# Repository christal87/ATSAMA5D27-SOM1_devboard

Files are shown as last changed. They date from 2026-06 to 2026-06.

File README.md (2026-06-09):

# ATSAMA5D27-SOM1_devboard

A custom SAMA5D27 development board I made a while ago for personal experimentation. It's exposing the parallel NAND flash interface to get some hands-on experience using that as a traditional embedded boot device.  

#### TODO:
- [x] PMIC power sequencing works, voltage regulation feedbacks valid, ripple low
- [x] board unique ID readable
- [x] serial console works
- [x] RTC backup supercap works
- [x] default SDMMC0 boots
- [x] USB host VBUS present
- [x] USB High Speed host works
- [x] NAND r/w test OK
- [ ] Configure NAND IOSET and boot config
- [ ] Implement NAND support in the at91bootstrap 2nd level bootloader and U-Boot
- [ ] Compile a kernel and make a rootfs that boots from NAND (buildroot/linux4sam custom board and kernel configs)
- [ ] test (Q)SPI interfaces
- [ ] use (Q)SPI to store the bootloader as NVM
- [ ] test other interfaces (JTAG, UARTs, USB device, ethernet, I^2C, SPI, PIOBU, HSIC)
- [ ] bonus: design and add an eMMC breakout board

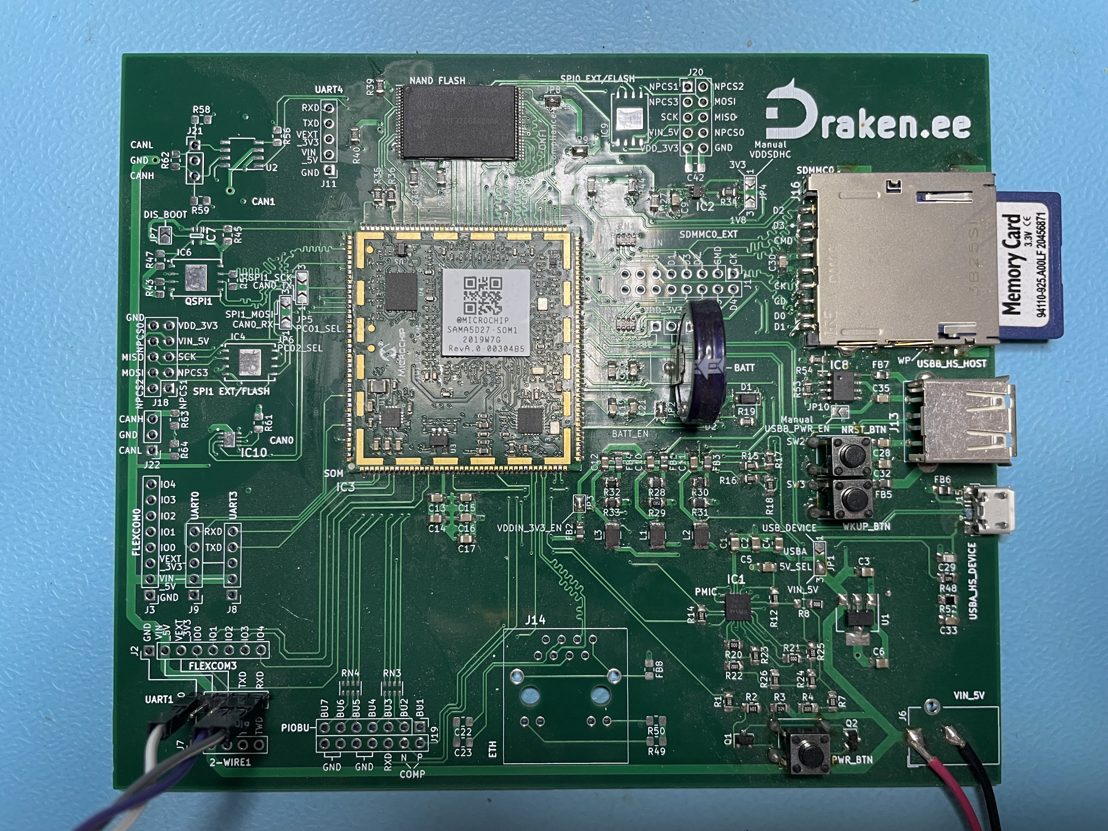
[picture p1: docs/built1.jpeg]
ATSAMA5D27-SOM1_devboard_built1 ATSAMA5D27-SOM1 devboard built


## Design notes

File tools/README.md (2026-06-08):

# sam-ba v3.7 boot assistant tool cheat sheet (via serial)

#### Board serial connection test by reading the device's unique ID
```
./sam-ba -p serial:ttyUSB0 -b sama5d27-som1 -a readuniqueid
```

#### This is the default state of boot config registers and fuses before changes

Read fuse:  
```
./sam-ba -t 5 -p serial:ttyUSB0 -b sama5d27-som1 -a bootconfig -c readcfg:fuse
Opening serial port 'ttyUSB0'
Connection opened.
Executing command 'readcfg:fuse'
FUSE=0x00000000 / QSPI0_IOSET1,QSPI1_IOSET1,SPI0_IOSET1,SPI1_IOSET1,NFC_IOSET1,SDMMC0,SDMMC1,UART1_IOSET1,JTAG_IOSET1
Connection closed.
```

Read BUREG[0:3]:  
```
./sam-ba -t 5 -p serial:ttyUSB0 -b sama5d27-som1 -a bootconfig -c readcfg:bureg0
Opening serial port 'ttyUSB0'
Connection opened.
Executing command 'readcfg:bureg0'
BUREG0=0x00000000 / QSPI0_IOSET1,QSPI1_IOSET1,SPI0_IOSET1,SPI1_IOSET1,NFC_IOSET1,SDMMC0,SDMMC1,UART1_IOSET1,JTAG_IOSET1
Connection closed.

./sam-ba -t 5 -p serial:ttyUSB0 -b sama5d27-som1 -a bootconfig -c readcfg:bureg1
Opening serial port 'ttyUSB0'
Connection opened.
Executing command 'readcfg:bureg1'
BUREG1=0x00000000 / QSPI0_IOSET1,QSPI1_IOSET1,SPI0_IOSET1,SPI1_IOSET1,NFC_IOSET1,SDMMC0,SDMMC1,UART1_IOSET1,JTAG_IOSET1
Connection closed.

./sam-ba -t 5 -p serial:ttyUSB0 -b sama5d27-som1 -a bootconfig -c readcfg:bureg2
Opening serial port 'ttyUSB0'
Connection opened.
Executing command 'readcfg:bureg2'
BUREG2=0x00000000 / QSPI0_IOSET1,QSPI1_IOSET1,SPI0_IOSET1,SPI1_IOSET1,NFC_IOSET1,SDMMC0,SDMMC1,UART1_IOSET1,JTAG_IOSET1
Connection closed.

./sam-ba -t 5 -p serial:ttyUSB0 -b sama5d27-som1 -a bootconfig -c readcfg:bureg3
Opening serial port 'ttyUSB0'
Connection opened.
Executing command 'readcfg:bureg3'
BUREG3=0x00000000 / QSPI0_IOSET1,QSPI1_IOSET1,SPI0_IOSET1,SPI1_IOSET1,NFC_IOSET1,SDMMC0,SDMMC1,UART1_IOSET1,JTAG_IOSET1
Connection closed.
```

Read BSCR:  
```
draken@christal-oldlaptop2:~/Downloads/sam-ba_3.5$ ./sam-ba -t 5 -p serial:ttyUSB0 -b sama5d27-som1 -a bootconfig -c readcfg:bscr
Opening serial port 'ttyUSB0'
Connection opened.
Executing command 'readcfg:bscr'
BSCR=0x00000000 / BUREG0
Connection closed.
```

#### Set SDMMC0 boot
Set up BUREG0 to boot from SDMMC0 with various IOSETs, then activate it by making it valid in the BSCR  

```
./sam-ba -t 5 -p serial:ttyUSB0 -b sama5d27-som1 -a bootconfig -c writecfg:bureg0:SDMMC0,SDMMC1_DISABLED,NFC_IOSET1,QSPI0_DISABLED,QSPI1_IOSET2,SPI0_IOSET1,SPI1_DISABLED,JTAG_IOSET3,QSPI_XIP_MODE,EXT_MEM_BOOT
./sam-ba -t 5 -p serial:ttyUSB0 -b sama5d27-som1 -a bootconfig -c writecfg:bscr:bureg0,valid
./sam-ba -t 5 -p serial:ttyUSB0 -b sama5d27-som1 -a bootconfig -c readcfg:bscr
```

#### SDMMC read test into file

Read 1024 bytes at offset 0 to a file from SDMMC0, IOSET1, 1st boot partition, 4-line I/O, at 3.3V level  
```
./sam-ba -p serial:ttyUSB0 -b sama5d27-som1 -t 5 -a sdmmc:0:1:1:4:4 -c read:firmware.bin:0x0:1024
```

#### NAND modification steps
**Notice: Only set fuses when they are to be permanent (in production)! Until then configs are held until RTC is powered down.**
1. Leave factory default DISABLE_BSCR (bit 22) as 0
2. Set BUREG_VALID if not already 1
3. Leave factory default BUREG_INDEX which has to be 0
4. Set up the correct BUREG_x according to the previously read index value
5. Set EXT_MEM_BOOT_ENABLE to 1 for using NAND, etc. flash
    - https://microchip.my.site.com/s/article/How-to-configure-the-PMECC
    - https://www.linux4sam.org/bin/view/Linux4SAM/PmeccConfigure
    - https://github.com/ARM-software/u-boot/blob/master/doc/README.nand
6. Set the correct PMECC header to configure the BCH algorithm for the NAND flash interface ECC controller
```
     example header: 0xc0098da5 - 0b1100 0 000000010 01 100 011011010 010 1
     key bits[31:28] - 1100 - decimal 12 or 0x0c must be written here to validate the content of the whole word
     bit[27] - not used, leave set to 0
     eccOffset bits[26:18] - 000000010 - 2: 2 byte offset of the first ECC byte in the spare zone
     sectorSize bits[17:16] - 01 - 1: For 1024 bytes per sector
     eccBitReq bits[15:13] - 100 - 4: 24-bit ECC
     spareSize bits[12:4] - 011011010 - 218 bytes
     nbSectorPerPage bits[3:1] - 010 - 2 sectors per page
     usePmecc bits[0] - 1 - use PMECC
```

#### NAND PMECC header according to the data sheet of a Micron MT29F32G08ABAAAWP-ITZ:A
Flash parameters:  
```
page (main) area size: 8192bytes
page OOB (spare) area size: 448bytes
block size: 1024K (56K OOB total per block)
plane size: 2 planes (2048blocks * 2) 
device size: 2 planes or 4096 blocks
erase block (sector) size: 1024k
minimum advised ECC: 8-bit BCH
```

Derived header: 0xc0e14387 - 0b 1100 0 000111000 01 010 000111000 011 1 (according to doc/nandflash.html)  
```
key bits[31:28] - 1100 - decimal 12 or 0x0c must be written here to validate the content of the whole word
bit[27] - not used, leave set to 0
eccOffset bits[26:18] - 000111000 - 56: datasheet: First spare area location: Byte 8192, 56 byte offset of the first ECC byte in the spare zone (app dependent) | Linux4sam: oob (spareSize) size - (PMECC encode data size * sector number per page): 56 - ( 14 x 8 ) = -56
sectorSize bits[17:16] - 01 - 1: For 1024 bytes per sector (determined by the user, sometimes called erase block size?)
eccBitReq bits[15:13] - 010 - 2: 8-bit ECC
spareSize bits[12:4] - 000111000 - 56 bytes (datasheet 114 bytes total / 8 sector = 56, spare area for ECC and wear levelling, minimum value: N = Number of ECC bytes x Sectors Per Page: 14 x 8 = 112)
nbSectorPerPage bits[3:1] - 011 - 8 sectors per page (depends on sectorSize and page size of the NAND, nbSectorPerPage * sectorSize = page size: 8 * 1024 = 8192)
usePmecc bits[0] - 1 - use PMECC
```

#### NAND flash read/write test (IOSET1, 8-bit bus, previously calculated PM ECC header)
First check if it's empty already then test by downloading a 1kByte dummy "hello world" binary to the target. Read back the previously written binary and verify using hexdump.  
```
./sam-ba -t 5 -p serial:ttyUSB0 -b sama5d27-som1 -a nandflash:1:8:0xc0e14387 -c read:firmware.bin::1024
./sam-ba -t 5 -p serial:ttyUSB0 -b sama5d27-som1 -a nandflash:1:8:0xc0e14387 -c write:firmware.bin
./sam-ba -t 5 -p serial:ttyUSB0 -b sama5d27-som1 -a nandflash:1:8:0xc0e14387 -c read:firmware_written.bin::1024
hexdump firmware_written.bin
```

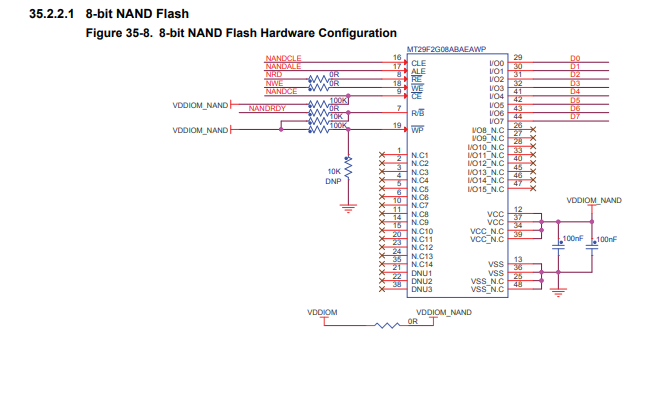
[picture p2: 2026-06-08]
docs/8bit_NAND_sch.png

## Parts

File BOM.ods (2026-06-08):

Ref. Des. | Available | Planned | Mouser URL | Qty | Mouser Part
C5, C10-C12 | CL21A475KPFNNNG | CL21A475KPFNNNG | https://hu.mouser.com/ProductDetail/Samsung-Electro-Mechanics/CL21A475KPFNNNG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 | 4 | 187-CL21A475KPFNNNG
C7 | 1F/5.5V | supercap |  | 1
C14, C17, C20, C21 | CL21A225KOFNNNE | CL21A225KOFNNNE | https://hu.mouser.com/ProductDetail/Samsung-Electro-Mechanics/CL21A225KOFNNNE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 | 4 | 187-CL21A225KOFNNNE
C8, C9, C13, C15, C16, C18, C19, C22, C23, C25-C28, C30, C31, C33-C38, C41-C43 | C0805C104M5RACTU | C0805C104M5RACTU | https://hu.mouser.com/ProductDetail/KEMET/C0805C104M5RACTU?qs=VOOUd%252Bza08qHu13WgNByHQ%3D%3D | 24 | 80-C0805C104M5R
C29 | C0805C200J5HACTU | C0805C200J5HACTU | https://hu.mouser.com/ProductDetail/KEMET/C0805C200J5HACTU?qs=W0yvOO0ixfGLt%252BzU2G34sQ%3D%3D | 1 | 80-C0805C200J5HACTU
C1-C4, C6, C24, C32 | CL21A106KAYNNNG | CL21A106KAYNNNG | https://hu.mouser.com/ProductDetail/Samsung-Electro-Mechanics/CL21A106KAYNNNG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 | 7 | 187-CL21A106KAYNNNG
C39, C40 | C0805C561M5RACTU | C0805C561M5RACTU | https://hu.mouser.com/ProductDetail/KEMET/C0805C561M5RACTU?qs=dntjzo9IpHrXGYTvsoaVYg%3D%3D | 2 | 80-C0805C561M5RACTU
D1 | STPS1L60ZF | STPS1L60ZF | https://hu.mouser.com/ProductDetail/STMicroelectronics/STPS1L60ZF?qs=xjeEZJU9OeMcvgJ4Z2%252BLPg%3D%3D | 1 | 511-STPS1L60ZF
D2 | BAT54C | BAT54C | https://hu.mouser.com/ProductDetail/Diotec-Semiconductor/BAT54C?qs=OlC7AqGiEDmkBJ3TS7AJwQ%3D%3D | 1 | 637-BAT54C
FB1-FB8 | BLM21SP181SH1D | BLM21SP181SH1D | https://hu.mouser.com/ProductDetail/Murata-Electronics/BLM21SP181SH1D?qs=byeeYqUIh0PxkBeBHE6ZPA%3D%3D | 8 | 81-BLM21SP181SH1D
IC1 | MIC23451-AAAYFL-T5 | MIC23451-AAAYFL-T5 | https://hu.mouser.com/ProductDetail/Microchip-Technology/MIC23451-AAAYFL-T5?qs=Y3Q3JoKAO1SH2PbgnVFIbQ%3D%3D | 1 | 998-MIC23451-AAAYFL
IC2 | TMUX1219DCKR | TMUX1219DCKR | https://hu.mouser.com/ProductDetail/Texas-Instruments/TMUX1219DCKR?qs=T3oQrply3y%252BxotOOfamVjQ%3D%3D | 1 | 595-TMUX1219DCKR
IC3 | ATSAMA5D27-SOM1 | ATSAMA5D27-SOM1 |  | 1
IC5 | MT29F32G08ABAAAWP-ITZ:A | MT29F32G08CBADBWP-12IT:D | https://hu.mouser.com/ProductDetail/Micron/MT29F32G08ABAAAWP-ITZA?qs=rrS6PyfT74fB1JX2ERU8Ug%3D%3D | 1 | 340-200226-TRAY
IC4, IC6, IC9 | IS25LP512M-JLLE | IS25LP512M-JLLE | https://hu.mouser.com/ProductDetail/ISSI/IS25LP512M-JLLE?qs=W0yvOO0ixfEtOjO9H9UVUg%3D%3D | 3 | 870-IS25LP512M-JLLE
IC7 | NL17SZ126DFT2G | NL17SZ126DFT2G | https://hu.mouser.com/ProductDetail/onsemi/NL17SZ126DFT2G-L22038?qs=vvQtp7zwQdOwMaO9ubYIuw%3D%3D | 1 | 863-Z126DFT2G-L22038
IC8 | MIC2075-1YM (/w th. Shdn.) | MIC2025-1YM | https://hu.mouser.com/ProductDetail/Microchip-Technology/MIC2075-1YM?qs=aiLzH1moG31jWXLy5NeZyA%3D%3D | 1 | 998-MIC2075-1YM
IC10 | ATA6561-GBQW-N | ATA6561-GBQW-N | https://hu.mouser.com/ProductDetail/Microchip-Technology/ATA6561-GBQW-N?qs=y6ZabgHbY%252BxuRHjTmdpZUA%3D%3D | 1 | 579-ATA6561-GBQW-N
J2, J3 | 22-28-4080 | 22-28-4080 |  | 2
J4 | 22-28-4020 | 22-28-4020 |  | 1
J5 | 77313-101-10LF | 77313-101-10LF |  | 1
J6 | PJ-102AH | PJ-102AH | https://hu.mouser.com/ProductDetail/CUI-Devices/PJ-102AH?qs=WyjlAZoYn50Yq4CrVLCXLw%3D%3D | 1 | 490-PJ-102AH
J7-J11 | 22-28-4050 | 22-28-4050 |  | 5
J13 | 87520-0010BLF | 87520-0010BLF | https://hu.mouser.com/ProductDetail/Amphenol-FCI/87520-0010BLF?qs=x6EjVpvqMVP%2F2to87x7cdQ%3D%3D | 1 | 649-87520-0010BLF
J14 | 5-2337992-4 (w/o PoE: KRJ45-109NL) | chinese eth magnetics | https://hu.mouser.com/ProductDetail/TE-Connectivity/5-2337992-4?qs=l4Gc20tDgJLHtal8kumJHQ%3D%3D | 1 | 571-5-2337992-4
J15 | 10103594-0001LF | 10103594-0001LF | https://hu.mouser.com/ProductDetail/Amphenol-FCI/10103594-0001LF?qs=EnLMdcWnKABYZwdMsmC%2Fag%3D%3D | 1 | 649-10103594-0001LF
J16 | DM1AA-SF-PEJ(82) | DM1AA-SF-PEJ(21) | https://hu.mouser.com/ProductDetail/Hirose-Connector/DM1AA-SF-PEJ82?qs=q%252B4FLHukgWBHaRKRr0HV%252Bw%3D%3D | 1 | 798-DM1AA-SF-PEJ82
J17 | 77313-101-16LF | 77313-101-16LF |  | 1
J18, J20 | 77313-101-10LF | 77313-101-10LF |  | 2
J19 | 77313-101-14LF | 77313-101-14LF |  | 1
J21, J22 | 22-28-4030 | 22-28-4030 |  | 2
L1-L3 | BRL3225T1R0M | BRL3225T1R0M | https://hu.mouser.com/ProductDetail/TAIYO-YUDEN/BRL3225T1R0M?qs=I6KAKw0tg2yR41WK9kXmMw%3D%3D | 3 | 963-BRL3225T1R0M
Q1, Q2 | BSS138-7-F | BSS138-7-F | https://hu.mouser.com/ProductDetail/Diodes-Incorporated/BSS138-7-F?qs=TJSU9qitBVRAP5gIAnNy0g%3D%3D | 2 | 621-BSS138-7-F
R28 | CRCW0805301KFKEA | CRCW0805301KFKEA | https://hu.mouser.com/ProductDetail/Vishay-Dale/CRCW0805301KFKEA?qs=YsYeyRVmgbTwvk7N3KDdww%3D%3D | 1 | 71-CRCW0805-301K-E3
R29 | CRCW0805158KFKEA | CRCW0805158KFKEA | https://hu.mouser.com/ProductDetail/Vishay-Dale/CRCW0805158KFKEA?qs=bMjB6bAaLEPYp%2Fg%252B8t1fcA%3D%3D | 1 | 71-CRCW0805158KFKEA
R30, R32 | CRCW0805309KFKEA | CRCW0805309KFKEA | https://hu.mouser.com/ProductDetail/Vishay-Dale/CRCW0805309KFKEA?qs=TrAHXYCGmqzIoat3yDoJTQ%3D%3D | 2 | 71-CRCW0805309KFKEA
R31, R33 | CRCW080571K5FKEA | CRCW080571K5FKEA | https://hu.mouser.com/ProductDetail/Vishay-Dale/CRCW080571K5FKEA?qs=Lu3mkJd%252BoBEibXcVy2xPUw%3D%3D | 2 | 71-CRCW0805-71.5K-E3
R6-R8, R10, R20, R21, R34-R36, R38, R60, R61, R63, R64 | CRCW08050000Z0EAC | CRCW08050000Z0EAC | https://hu.mouser.com/ProductDetail/Vishay-Dale/CRCW08050000Z0EAC?qs=E3Y5ESvWgWMnvHb9ZvShmA%3D%3D | 14 | 71-CRCW08050000Z0EAC
R42 | CRCW080510K0FKEAC | CRCW080510K0FKEAC |  | 1
R2, R3, R9, R11, R13, R17, R37, R40, R48 | CRCW0805100KJNEAC | CRCW0805100KJNEAC | https://hu.mouser.com/ProductDetail/Vishay-Dale/CRCW0805100KJNEAC?qs=E3Y5ESvWgWMMFQOyHSPe4Q%3D%3D | 9 | 71-CRCW0805100KJNEAC
R49, R50 | CRCW0805470RFKEAC | CRCW0805470RFKEAC | https://hu.mouser.com/ProductDetail/Vishay-Dale/CRCW0805470RFKEAC?qs=E3Y5ESvWgWPsF5leBpDSrQ%3D%3D | 2 | 71-CRCW0805470RFKEAC
R52 | CRCW0805200KJNEA | CRCW0805200KJNEAC | https://hu.mouser.com/ProductDetail/Vishay-Dale/CRCW0805200KJNEA?qs=t6Mf8e9K%2Fuk6Viblk4xGKg%3D%3D | 1 | 71-CRCW0805200KJNEA
R1, R4, R5, R14, R18, R22-R27, R39, R41, R43-R47, R51, R53, R54, R56 | CRCW080510K0FKEAC | CRCW080510K0FKEAC | https://hu.mouser.com/ProductDetail/Vishay-Dale/CRCW080510K0FKEAC?qs=E3Y5ESvWgWORadmUijPtxQ%3D%3D | 22 | 71-CRCW080510K0FKEAC
R55 | CRCW080522K0FKEAC | CRCW080522K0FKEAC | https://hu.mouser.com/ProductDetail/Vishay-Dale/CRCW080522K0FKEAC?qs=E3Y5ESvWgWM%252BLh7gNR1oHw%3D%3D | 1 | 71-CRCW080522K0FKEAC
R57 | CRCW08054K70FKEAC | CRCW08054K70FKEAC | https://hu.mouser.com/ProductDetail/Vishay-Dale/CRCW08054K70FKEAC?qs=E3Y5ESvWgWOQAAVugewEHA%3D%3D | 1 | 71-CRCW08054K70FKEAC
R12, R15, R16, R19, R58, R59 | CRCW0805100RFKEAC | CRCW0805100RFKEAC | https://hu.mouser.com/ProductDetail/Vishay-Dale/CRCW0805100RFKEAC?qs=E3Y5ESvWgWM6LN%2Fsc41QGg%3D%3D | 6 | 71-CRCW0805100RFKEAC
R62 | CRCW0805120RFKEAC | CRCW0805120RFKEAC | https://hu.mouser.com/ProductDetail/Vishay-Dale/CRCW0805120RFKEAC?qs=E3Y5ESvWgWNkSFxCW%252BJprQ%3D%3D | 1 | 71-CRCW0805120RFKEAC
RN1, RN2 | CAT16-683J4LF | CAY16-683J4LF | https://hu.mouser.com/ProductDetail/Bourns/CAT16-683J4LF?qs=RWPSkEkPOWwoZjhdciY8Mw%3D%3D | 2 | 652-CAT16-683J4LF
RN3, RN4 | CAT16-331J4LF | CAY16-331J4LF | https://hu.mouser.com/ProductDetail/Bourns/CAT16-331J4LF?qs=FaUPen95qPZGHrhxk7z1MA%3D%3D | 2 | 652-CAT16-331J4LF
SW1-SW3 | PTS645SM43SMTR92LFS | simple pushbutton |  | 3
U1 | AZ1117CR-3.3TRG1 | LM1117-3.3 | https://hu.mouser.com/ProductDetail/Diodes-Incorporated/AZ1117CR-3.3TRG1?qs=FKu9oBikfSlEg7waHw2tMw%3D%3D | 1 | 621-AZ1117CR-3.3TRG1
U2 | MCP2551-I/SN | MCP2551-I/SN | https://hu.mouser.com/ProductDetail/Microchip-Technology/MCP2551-I-SN?qs=9y3LFqDLL8L5zFfqqxdOHg%3D%3D | 1 | 579-MCP2551-I/SN

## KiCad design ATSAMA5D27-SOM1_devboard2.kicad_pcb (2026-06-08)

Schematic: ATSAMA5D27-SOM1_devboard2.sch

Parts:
C1, C2, C3, C4, C6, C24, C32: 10uF/25V; C_0805_2012Metric_Pad1.15x1.40mm_HandSolder; Part CL21A106KAYNNNG
C5, C10, C11, C12: 4.7uF/10V; C_0805_2012Metric_Pad1.15x1.40mm_HandSolder; Part CL21A475KPFNNNG
C7: 1F/5.5V; C_Disc_D11.0mm_W5.0mm_P5.00mm
C8, C9, C13, C15, C16, C18, C19, C22, C23, C25, C26, C27, C28, C30, C31, C33, C34, C35, C36, C37, C38, C41, C42, C43: 100nF; C_0805_2012Metric_Pad1.15x1.40mm_HandSolder; Part C0805C104M5RACTU
C14, C17, C20, C21: 2.2uF/16V; C_0805_2012Metric_Pad1.15x1.40mm_HandSolder; Part CL21A225KOFNNNE
C29: 20pF; C_0805_2012Metric_Pad1.15x1.40mm_HandSolder; Part C0805C200J5HACTU
C39, C40: 560pF; C_0805_2012Metric_Pad1.15x1.40mm_HandSolder; Part C0805C561M5RACTU
D1: STPS1L60ZF; D_SOD-123; Part STPS1L60ZF
D2: BAT54C; SOT-23; Part BAT54C
FB1, FB2, FB3, FB4, FB5, FB6, FB7, FB8: 180R; L_0805_2012Metric_Pad1.15x1.40mm_HandSolder; Part BLM21SP181SH1D
IC1: MIC23451-AAAYFL-T5; MIC23451AAAYFLT5; Manufacturer_Part_Number MIC23451-AAAYFL-T5; Mouser Part Number 998-MIC23451-AAAYFL
IC2: TMUX1219DCKR; SOT65P210X110-6N; Manufacturer_Part_Number TMUX1219DCKR; Mouser Part Number 595-TMUX1219DCKR
IC3: ATSAMA5D27-SOM1; ATSAMA5D27SOM1; Manufacturer_Part_Number ATSAMA5D27-SOM1; Mouser Part Number 556-ATSAMA5D27-SOM1
IC4, IC6, IC9: IS25LP512M-JLLE; SON127P800X600X80-9N; Manufacturer_Part_Number IS25LP512M-JLLE; Mouser Part Number 870-IS25LP512M-JLLE
IC5: MT29F32G08CBADBWP-12IT:D; SOP50P2000X120-48N; Manufacturer_Part_Number MT29F32G08ABAAAWP-ITZ:A; Mouser Part Number 340-200226-TRAY
IC7: NL17SZ126DFT2G; SOT65P210X110-5N; Manufacturer_Part_Number NL17SZ126DFT2G; Mouser Part Number 863-NL17SZ126DFT2G
IC8: MIC2025-1YM; SOIC127P602X173-8N; Manufacturer_Part_Number MIC2025-1YM; Mouser Part Number 998-MIC2025-1YM
IC10: ATA6561-GBQW-N; SON65P300X300X90-9N-D; Manufacturer_Part_Number ATA6561-GBQW-N; Mouser Part Number 579-ATA6561-GBQW-N
J2, J3: 22-28-4080; PinHeader_1x08_P2.54mm_Vertical; Part 22-28-4080
J4: 22-28-4020; PinHeader_1x02_P2.54mm_Vertical; Part 22-28-4020
J5: 77313-101-10LF; PinHeader_2x05_P2.54mm_Vertical_SMD; Part 77313-101-10LF
J6: PJ-102AH; BarrelJack_CUI_PJ-102AH_Horizontal; Part PJ-102AH
J7, J8, J9, J10, J11: 22-28-4050; PinHeader_1x05_P2.54mm_Vertical; Part 22-28-4050
J13: 87520-0010BLF; 875200010BLF; Manufacturer_Part_Number 87520-0010BLF; Mouser Part Number 649-87520-0010BLF
J14: 5-2337992-4 (w/o PoE: KRJ45-109NL); 523379924; Manufacturer_Part_Number 5-2337992-4; Mouser Part Number 571-5-2337992-4
J15: 10103594-0001LF; USB_Micro-B_Amphenol_10103594-0001LF_Horizontal; Part 10103594-0001LF
J16: DM1AA-SF-PEJ_21_; DM1AA-SF-PEJ_21__1; Manufacturer_Part_Number DM1AA-SF-PEJ(21); Mouser Part Number 798-DM1AA-SF-PEJ21
J17: 77313-101-16LF; PinHeader_2x08_P2.54mm_Vertical; Part 77313-101-16LF
J18, J20: 77313-101-10LF; PinHeader_2x05_P2.54mm_Vertical; Part 77313-101-10LF
J19: 77313-101-14LF; PinHeader_2x07_P2.54mm_Vertical; Part 77313-101-14LF
J21, J22: 22-28-4030; PinHeader_1x03_P2.54mm_Vertical; Part 22-28-4030
JP1, JP4, JP5, JP6: SolderJumper3; SolderJumper-3_P2.0mm_Open_TrianglePad1.0x1.5mm_NumberLabels; Part 22-28-4030
JP2, JP3, JP7, JP8, JP9, JP10: SolderJumper2; SolderJumper-2_P1.3mm_Open_TrianglePad1.0x1.5mm; Part 22-28-4020
L1, L2, L3: 1uH/2.2A; L_1210_3225Metric_Pad1.42x2.65mm_HandSolder; Part BRL3225T1R0M
Q1, Q2: BSS138; SOT-23
R1, R4, R5, R14, R18, R22, R23, R24, R25, R26, R27, R39, R41, R44, R45, R46, R47, R51, R53, R54, R56: 10k; R_0805_2012Metric_Pad1.15x1.40mm_HandSolder; Part CRCW080510K0FKEAC
R2, R3, R9, R11, R13, R17, R37, R40, R48: 100k; R_0805_2012Metric_Pad1.15x1.40mm_HandSolder; Part CRCW0805100KJNEAC
R6, R7, R8, R10, R20, R21, R34, R35, R36, R38, R60, R61, R63, R64: 0R; R_0805_2012Metric_Pad1.15x1.40mm_HandSolder; Part CRCW08050000Z0EAC
R12, R15, R16, R19, R58, R59: 100R; R_0805_2012Metric_Pad1.15x1.40mm_HandSolder; Part CRCW0805100RFKEAC
R28: 301k; R_0805_2012Metric_Pad1.15x1.40mm_HandSolder; Part CRCW0805301KFKEA
R29: 158k; R_0805_2012Metric_Pad1.15x1.40mm_HandSolder; Part CRCW0805158KFKEA
R30, R32: 309k; R_0805_2012Metric_Pad1.15x1.40mm_HandSolder; Part CRCW0805309KFKEA
R31, R33: 71.5k; R_0805_2012Metric_Pad1.15x1.40mm_HandSolder; Part CRCW080571K5FKEA
R42: 10k (DNP); R_0805_2012Metric_Pad1.15x1.40mm_HandSolder; Part CRCW080510K0FKEAC
R43: 10k; R_0805_2012Metric_Pad1.15x1.40mm_HandSolder; part CRCW080510K0FKEAC
R49, R50: 470R; R_0805_2012Metric_Pad1.15x1.40mm_HandSolder; Part CRCW0805470RFKEAC
R52: 200k; R_0805_2012Metric_Pad1.15x1.40mm_HandSolder; Part CRCW0805200KJNEAC
R55: 22k; R_0805_2012Metric_Pad1.15x1.40mm_HandSolder; Part CRCW080522K0FKEAC
R57: 4k7; R_0805_2012Metric_Pad1.15x1.40mm_HandSolder; Part CRCW08054K70FKEAC
R62: 120R; R_0805_2012Metric_Pad1.15x1.40mm_HandSolder; Part CRCW0805120RFKEAC
RN1, RN2: 68k; R_Cat16-4; Part CAY16-683J4LF
RN3, RN4: 330R; R_Cat16-4; Part CAY16-331J4LF
SW1, SW2, SW3: PTS645SM43SMTR92LFS; SW_SPST_PTS645; Part PTS645SM43SMTR92LFS
U1: NCP1117-3.3_SOT223; SOT-223-3_TabPin2
U2: MCP2551-I-SN; SOIC-8_3.9x4.9mm_P1.27mm

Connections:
BB_PWR_GOOD: IC1.13 (PG3), IC3.28 (PD08/NANDRDY), R14.1
CAN0_RX: C36.1, IC10.4 (RXD), JP6.1 (A)
CAN0_TX: IC10.1 (TXD), JP5.1 (A)
CAN1_RX: IC3.114 (PC27/PCK1/CANRX1/A16), R55.1, R56.1
CAN1_TX: IC3.115 (PC26/CANTX1/A15), U2.1 (TXD)
CLK_AUDIO: IC3.61 (CLK_AUDIO)
COMPN: IC3.64 (COMPN), J19.4
COMPP: IC3.63 (COMPP), J19.2
CS_QSPI1: IC6.1 (CE#), IC7.4 (OUT_Y), R47.2
DISABLE_BOOT: IC3.126 (DIS_BOOT), IC7.1 (OE), JP7.2, R45.2
D_UART1_RXD: IC3.23 (PD02/URXD1/A25), J10.5
D_UART1_TXD: IC3.24 (PD03/UTXD1/FIQ/NWAIT), J10.4
ETH_LED0: IC3.36 (ETH_LED0), J14.P11
ETH_RX+: IC3.38 (ETH_RXP), J14.P3
ETH_RX-: IC3.37 (ETH_RXM), J14.P6
ETH_TX+: IC3.41 (ETH_TXP), J14.P1
ETH_TX-: IC3.40 (ETH_TXM), J14.P2
FLEXCOM0_IO0: IC3.167 (PB28/LCDDAT17/FLEXCOM0_IO0/TIOA5), J3.4
FLEXCOM0_IO1: IC3.144 (PB29/LCDDAT18/FLEXCOM0_IO1/TIOB5), J3.5
FLEXCOM0_IO2: IC3.165 (PB30/LCDDAT19/FLEXCOM0_IO2/TCLK5), J3.6
FLEXCOM0_IO3: IC3.143 (PB31/LCDDAT20/FLEXCOM0_IO3), J3.7
FLEXCOM0_IO4: IC3.145 (PC00/LCDDAT21/FLEXCOM0_IO4), J3.8
FLEXCOM3_IO0: IC3.14 (PC20/ISI_D11/FLEXCOM3_IO0/A9), J2.4
FLEXCOM3_IO1: IC3.6 (PC19/ISI_D10/FLEXCOM3_IO1/A8), J2.5
FLEXCOM3_IO2: IC3.172 (PC18/ISI_D9/FLEXCOM3_IO2/A7), J2.6
FLEXCOM3_IO3: IC3.7 (PC21/ISI_PCK/FLEXCOM3_IO3/A10), J2.7
FLEXCOM3_IO4: IC3.11 (PC22/ISI_VSYNC/FLEXCOM3_IO4/A11), J2.8
FLEXCOM4_IO0: IC3.117 (PC28/FLEXCOM4_IO0/PCK2/A17)
FLEXCOM4_IO1: IC3.118 (PC29/FLEXCOM4_IO1/A18)
FLEXCOM4_IO2: IC3.120 (PC30/FLEXCOM4_IO2/A19)
FLEXCOM4_IO3: IC3.116 (PC31/FLEXCOM4_IO3/URXD3/A20)
FLEXCOM4_IO4: IC3.121 (PD00/FLEXCOM4_IO4/UTXD3/A23)
GND: C1.2, C2.2, C3.2, C4.2, C5.2, C6.2, C7.2, C8.2, C9.2, C10.2, C11.2, C12.2, C13.2, C14.2, C15.1, C16.1, C17.1, C18.1, C19.1, C20.1, C21.1, C22.2, C23.2, C24.2, C25.2, C26.2, C27.2, C28.2, C29.2, C30.2, C31.2, C32.2, C33.2, C34.2, C35.2, C36.2, C37.1, C38.2, C39.2, C40.2, C41.2, C42.2, C43.1, FB5.1, FB6.1, FB8.1, IC1.1 (PGND_1), IC1.2 (PGND_2), IC1.10 (PGND_3), IC1.11 (AGND_1), IC1.24 (AGND_2), IC1.27 (EP1), IC1.28 (EP2), IC2.3 (GND), IC3.1 (GND_00), IC3.10 (GND_01), IC3.18 (GND_02), IC3.26 (GND_03), IC3.31 (GND_04), IC3.39 (GND_05), IC3.42 (GND_06), IC3.43 (GND_07), IC3.50 (GND_08), IC3.56 (GND_09), IC3.62 (GND_10), IC3.66 (GND_11), IC3.69 (GND_12), IC3.72 (GND_13), IC3.75 (GND_14), IC3.88 (GND_15), IC3.89 (GND_16), IC3.98 (GND_17), IC3.107 (GND_18), IC3.130 (GND_19), IC3.131 (GND_20), IC3.149 (GND_21), IC3.166 (GND_22), IC3.171 (GND_23), IC3.176 (GND_24), IC4.4 (GND), IC5.13 (VSS_1), IC5.36 (VSS_2), IC6.4 (GND), IC7.3 (GND), IC8.3 (GND), IC9.4 (GND), IC10.2 (GND), IC10.9 (EP), J2.1, J3.1, J5.3, J5.5, J5.9, J6.2, J7.1, J8.1, J9.1, J10.1, J11.1, J13.4, J14.P10, J15.5 (GND), J16.3, J16.12 (WRITE_PROTECTION_SWITCH_2), J17.14, J17.15, J17.16, J18.10, J19.8, J19.10, J19.12, J19.14, J20.10, J21.2, J22.2, JP7.1, JP8.2, Q1.2 (S), Q2.2 (S), R5.2, R27.2, R29.2, R31.2, R33.2, R42.1, R52.1, R54.2, R55.2, R57.2, R60.1, SW1.2, SW2.2, SW3.2, U1.1 (GND), U2.2 (VSS)
HSIC_DATA: IC3.74 (DATA), J4.2
HSIC_STROBE: IC3.73 (STROBE), J4.1
JTAG_TCK: IC3.53 (PD27/JTAG_TCK), J5.4, R13.1
JTAG_TDI: IC3.51 (PD28/JTAG_TDI), J5.8, R11.1
JTAG_TDO: IC3.52 (PD29/JTAG_TDO), J5.6
JTAG_TMS: IC3.54 (PD30/JTAG_TMS), J5.2, R9.1
NAND_ALE: IC3.119 (PB00/SPI0_MOSI/PWMH1), IC5.17 (ALE)
NAND_CE: IC3.93 (PA31/SPI0_MISO/PWML0/CLASSD_L3), IC5.9 (CE#), R37.1
NAND_CLE: IC3.122 (PB01/SPI0_SPCK/PWML1/CLASSD_R0), IC5.16 (CLE)
NAND_D0: IC3.106 (PA22/FLEXCOM1_IO2/SPI1_SPCK/SDMMC1_CK/Q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), IC5.29 (DQ0)
NAND_D1: IC3.102 (PA23/FLEXCOM1_IO1/SPI1_MOSI/QSPI0_CS), IC5.30 (DQ1)
NAND_D2: IC3.99 (PA24/FLEXCOM1_IO0/SPI1_MISO/QSPI0_IO0), IC5.31 (DQ2)
NAND_D3: IC3.97 (PA25/FLEXCOM1_IO3/SPI1_NPCS0/QSPI0_IO1), IC5.32 (DQ3)
NAND_D4: IC3.100 (PA26/FLEXCOM1_IO4/SPI1_NPCS1/QSPI0_IO2), IC5.41 (DQ4)
NAND_D5: IC3.90 (PA27/TIOA1/SPI0_NPCS2/SPI1_NPCS2/SDMMC1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), IC5.42 (DQ5)
NAND_D6: IC3.95 (PA28/TIOB1/SPI0_NPCS3/SPI1_NPCS3/SDMMC1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), IC5.43 (DQ6)
NAND_D7: IC3.96 (PA29/TCLK1/SPI0_NPCS1/SDMMC1_WP/CLASSD_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), IC5.44 (DQ7)
NAND_RDY: IC3.138 (PC08/LCDDEN/FIQ/PCK0/UTXD1), R35.2
NAND_RE: IC3.124 (PB02/PWMFI0/CLASSD_R1), R36.2
NAND_WE: IC3.94 (PA30/SPI0_NPCS0/PWMH0/SDMMC1_CD/CLASSD_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), R38.2
NRST: IC3.60 (NRST), R10.1, R15.2
unnamed: C1.1, C2.1, C4.1, IC1.5 (PVIN2), IC1.8 (PVIN3), IC1.25 (PVIN1), JP1.2 (C), R8.2, R12.2
unnamed: C5.1, IC1.3 (AVIN1), IC1.6 (AVIN2), IC1.9 (AVIN3), R12.1
unnamed: C7.1, D2.1, R19.1
unnamed: C8.1, D2.3, JP2.1
unnamed: C22.1, J14.P4
unnamed: C23.1, J14.P5
unnamed: C28.1, C32.1, FB7.2, J13.1
unnamed: C39.1, R58.2
unnamed: C40.1, R59.2
unnamed: C41.1, IC10.5 (VIO), R61.2
unnamed: C43.2, R63.2, R64.1
unnamed: D1.1 (K), R19.2
unnamed: FB2.2, JP3.2
unnamed: FB5.2, J13.MH1, J13.MH2
unnamed: FB6.2, J15.6 (Shield)
unnamed: FB7.1, IC8.6 (OUT_1), IC8.8 (OUT_2)
unnamed: FB8.2, J14.MH1, J14.MH2, J14.P8
unnamed: IC1.4 (SW2), L1.1
unnamed: IC1.7 (SW3), L3.1
unnamed: IC1.14 (FB3), R32.2, R33.1
unnamed: IC1.15 (EN3), R20.2, R22.2, R23.2
unnamed: IC1.16 (PG2), R20.1
unnamed: IC1.17 (FB2), R28.2, R29.1
unnamed: IC1.19 (EN2), R21.2, R24.2, R25.2
unnamed: IC1.20 (PG1), R21.1
unnamed: IC1.21 (EN1), R26.2
unnamed: IC1.23 (FB1), R30.2, R31.1
unnamed: IC1.26 (SW1), L2.1
unnamed: IC2.5 (D), R34.2
unnamed: IC3.141 (PC01/LCDDAT22/CANTX0/SPI1_SPCK/I2SCK0), JP5.2 (C)
unnamed: IC3.146 (PC02/LCDDAT23/CANRX0/SPI1_MOSI/I2SMCK0), JP6.2 (C)
unnamed: IC5.7 (R/B#), R35.1, R39.1
unnamed: IC5.8 (RE#), R36.1
unnamed: IC5.18 (WE#), R38.1
unnamed: IC5.19 (WP#), R40.1, R42.2
unnamed: IC5.25 (DNU/VSSQ_1), IC5.48 (DNU/VSSQ_2), JP8.1
unnamed: IC5.34 (DNU/VCCQ_1), IC5.39 (DNU/VCCQ_2), JP9.1
unnamed: IC10.6 (CANL), J22.1, R64.2
unnamed: IC10.7 (CANH), J22.3, R63.1
unnamed: IC10.8 (STBY), R60.2
unnamed: J5.7, R6.1
unnamed: J5.10, R10.2
unnamed: J14.P9, R49.2
unnamed: J14.P12, R50.2
unnamed: J19.1, RN3.8 (R1.2)
unnamed: J19.3, RN3.7 (R2.2)
unnamed: J19.5, RN3.6 (R3.2)
unnamed: J19.7, RN3.5 (R4.2)
unnamed: J19.9, RN4.8 (R1.2)
unnamed: J19.11, RN4.7 (R2.2)
unnamed: J19.13, RN4.6 (R3.2)
unnamed: J21.1, R58.1, R62.2, U2.6 (CANL)
unnamed: J21.3, R59.1, R62.1, U2.7 (CANH)
unnamed: Q1.1 (G), R1.1, R2.1
unnamed: Q1.3 (D), Q2.1 (G), R3.1, SW1.1
unnamed: Q2.3 (D), R4.2, R7.2
unnamed: R5.1, R6.2
unnamed: R15.1, R17.1, SW2.1
unnamed: R16.1, R18.1, SW3.1
unnamed: R7.1, R8.1, R22.1, R24.1, R26.1
unnamed: R56.2, U2.4 (RXD)
unnamed: R57.1, U2.8 (Rs)
PA21: IC3.103 (PA21/PCK2/IRQ/TCLK0/SDMMC1_DAT3/NANDRDY)
PB11: IC3.148 (PB11/LCDDAT0/URXD3/PDMDAT0)
PB12: IC3.151 (PB12/LCDDAT1/UTXD3/PDMCLK0)
PB13: IC3.155 (PB13/LCDDAT2/PCK1)
PB14: IC3.150 (PB14/LCDDAT3/TK1/I2SMCK1)
PB15: IC3.162 (PB15/LCDDAT4/TF1/I2SCK1)
PB16: IC3.154 (PB16/LCDDAT5/TD1/I2SWS1)
PB17: IC3.157 (PB17/LCDDAT6/RD1/I2SDI1)
PB18: IC3.152 (PB18/LCDDAT7/RK1/I2SDO1)
PB19: IC3.158 (PB19/LCDDAT8/RF1/TIOA3)
PB20: IC3.156 (PB20/LCDDAT9/TK0/TIOB3/PCK1)
PB21: IC3.164 (PB21/LCDDAT10/TF0/TCLK3/FLEXCOM3_IO2)
PB22: IC3.161 (PB22/LCDDAT11/TD0/TIOA2/FLEXCOM3_IO1)
PB23: IC3.160 (PB23/LCDDAT12/RD0/TIOB2/FLEXCOM3_IO0)
PB24: IC3.168 (PB24/LCDDAT13/RK0/TCLK2/FLEXCOM3_IO3)
PB25: IC3.159 (PB25/LCDDAT14/RF0/FLEXCOM3_IO4)
PC9: IC3.2 (PC09/FIQ/ISI_D0/TIOA4)
PC10: IC3.9 (PC10/ISI_D1/TIOB4/CANTX0)
PC11: IC3.175 (PC11/ISI_D2/TCLK4/CANRX0/A0/NBS0)
PC14: IC3.8 (PC14/ISI_D5/TD0/A3)
PC15: IC3.12 (PC15/ISI_D6/RD0/A4)
PC16: IC3.174 (PC16/ISI_D7/RK0/A5)
PC17: IC3.5 (PC17/ISI_D8/RF0/A6)
PC23: IC3.170 (PC23/ISI_HSYNC/A12)
PC24: IC3.13 (PC24/ISI_MCK/A13)
PC25: IC3.173 (PC25/ISI_FIELD/A14)
PD1: IC3.113 (PD01/A24)
PD6: IC3.22 (PD06/PCK1/NCS2)
PD7: IC3.25 (PD07/NWR1/NBS1)
PD22: IC3.20 (PD22/EEPROM_TWCK_PD22)
PD23: IC3.30 (PD23/URXD2/AD4)
PD24: IC3.29 (PD24/UTXD2/AD5)
PD25: IC3.110 (PD25/AD6)
PD26: IC3.34 (PD26/AD7)
PIOBU1: IC3.33 (PIOBU1), RN3.1 (R1.1)
PIOBU2: IC3.44 (PIOBU2), RN3.2 (R2.1)
PIOBU3: IC3.48 (PIOBU3), RN3.3 (R3.1)
PIOBU4: IC3.47 (PIOBU4), RN3.4 (R4.1)
PIOBU5: IC3.46 (PIOBU5), RN4.1 (R1.1)
PIOBU6: IC3.59 (PIOBU6), RN4.2 (R2.1)
PIOBU7: IC3.45 (PIOBU7), RN4.3 (R3.1)
QSPI1_CS: IC3.127 (PB06/TIOA2/PWML2/QSPI1_CS), IC7.2 (IN_A)
QSPI1_IO0: IC3.133 (PB07/TIOB2/PWMH3/QSPI1_IO0), IC6.5 (SI_(IO0))
QSPI1_IO1: IC3.128 (PB08/TCLK3/PWML3/QSPI1_IO1), IC6.2 (SO_(IO1))
QSPI1_IO2: IC3.132 (PB09/TIOA3/PWMFI1/QSPI1_IO2), IC6.3 (WP#_(IO2)), R43.2
QSPI1_IO3: IC3.135 (PB10/TIOB3/PWMEXTRG1/QSPI1_IO3), IC6.7 (HOLD#_OR_RESET#_(IO3)), R51.2
QSPI1_SCK: IC3.134 (PB05/TCLK2/PWMH2/QSPI1_SCK), IC6.6 (SCK)
RXD: IC3.32 (RXD), J19.6
SDMMC0_CD: IC3.91 (PA13/SDMMC0_CD/FLEXCOM3_IO1/D8), J16.6, R46.2
SDMMC0_CK: IC3.80 (PA00/SDMMC0_CK/QSPIO0_SLK/D0), J16.5, J17.1
SDMMC0_CMD: IC3.76 (PA01/SDMMC0_CMD/QSPI0_CS/D1), J16.2, J17.3, R41.2
SDMMC0_D0: IC3.83 (PA02/SDMMC0_DAT0/QSPI0_IO0/D2), J16.7, J17.11, RN1.1 (R1.1)
SDMMC0_D1: IC3.81 (PA03/SDMMC0_DAT1/QSPI0_IO1/D3), J16.8, J17.9, RN1.2 (R2.1)
SDMMC0_D2: IC3.84 (PA04/SDMMC0_DAT2/QSPI0_IO2/D4), J16.9, J17.5, RN1.4 (R4.1)
SDMMC0_D3: IC3.85 (PA05/SDMMC0_DAT3/QSPI0_IO3/D5), J16.1, J17.7, RN1.3 (R3.1)
SDMMC0_D4: IC3.86 (PA06/SDMMC0_DAT4/TIOA5/FLEXCOM2_IO0/D6), J17.2, RN2.1 (R1.1)
SDMMC0_D5: IC3.79 (PA07/SDMMC0_DAT5/TIOB5/FLEXCOM2_IO1/D7), J17.4, RN2.2 (R2.1)
SDMMC0_D6: IC3.78 (PA08/SDMMC0_DAT6/TCLK5/FLEXCOM2_IO2/NWE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), J17.6, RN2.3 (R3.1)
SDMMC0_D7: IC3.77 (PA09/SDMMC0_DAT7/TIOA4/FLEXCOM2_IO3/NCS3), J17.8, RN2.4 (R4.1)
SDMMC0_RSTN: IC3.82 (PA10/SDMMC0_RSTN/TIOB4/FLEXCOM2_IO4/A21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), J17.13
SDMMC0_VDDSEL: IC2.1 (SEL), IC3.87 (PA11/SDMMC0_VDDSEL/TCLK4/A22/NANDCLE), R27.1
SDMMC0_WP: IC3.92 (PA12/SDMMC0_WP/IRQ/NRD/NANDOE), J16.11 (WRITE_PROTECTION_SWITCH_1), R44.2
SHDN: IC3.35 (SHDN), R1.2
SPI0_MISO: IC3.112 (PA16/SPI0_MISO/TD1/QSPI0_IO0/I2SWS1/FLE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), IC9.2 (SO_(IO1)), J20.6
SPI0_MOSI: IC3.109 (PA15/SPI0_MOSI/TF1/QSPI0_CS/I2SCK1/FLEX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), IC9.5 (SI_(IO0)), J20.4
SPI0_NPCS0: IC3.108 (PA17/SPI0_NPCS0/RD1/QSPI0_IO1/I2SDI1/FL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), IC9.1 (CE#), J20.8
SPI0_NPCS1: IC3.105 (PA18/SPI0_NPCS1/RK1/QSPI0_IO2/I2SDO1/SD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), J20.1
SPI0_NPCS2: IC3.101 (PA19/SPI0_NPCS2/RF1/QSPI0_IO3/TIOA0/SDM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), J20.2
SPI0_NPCS3: IC3.104 (PA20/SPI0_NPCS3/TIOB0/SDMMC1_DAT2/D15), J20.3
SPI0_SCK: IC3.111 (PA14/SPI0_SPCK/TK1/QSPI0_SCK/I2SMCK1/FL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), IC9.6 (SCK), J20.5
SPI1_MISO: IC3.142 (PC03/LCDPWM/TIOA1/SPI1_MISO/I2SWS0), IC4.2 (SO_(IO1)), J18.6
SPI1_MOSI: IC4.5 (SI_(IO0)), J18.4, JP6.3 (B)
SPI1_NPCS0: IC3.136 (PC04/LCDDISP/TIOB1/SPI1_NPCS0/I2SDI0), IC4.1 (CE#), J18.8
SPI1_NPCS1: IC3.137 (PC05/LCDVSYNC/TCLK1/SPI1_NPCS1/I2SDO0), J18.1
SPI1_NPCS2: IC3.140 (PC06/LCDHSYNC/TWD1/SPI1_NPCS2), J18.2
SPI1_NPCS3: IC3.139 (PC07/LCDPCK/TWCK1/SPI1_NPCS3/URXD1), J18.3
SPI1_SCK: IC4.6 (SCK), J18.5, JP5.3 (B)
TWCK1: IC3.21 (PD05/TWCK1/NCS1), J7.4
TWD1: IC3.27 (PD04/TWD1/NCS0), J7.5
UART0_RXD: IC3.169 (PB26/LCDDAT15/URXD0), J9.5
UART0_TXD: IC3.163 (PB27/LCDDAT16/UTXD0), J9.4
UART3_RXD: IC3.3 (PC12/ISI_D3/URXD3/TK0/A1), J8.5
UART3_TXD: IC3.4 (PC13/ISI_D4/UTXD3/TF0/A2), J8.4
UART4_RXD: IC3.123 (PB03/URXD4/IRQ/PWMEXTRG0/CLASSD_R2), J11.5
UART4_TXD: IC3.125 (PB04/UTXD4/FIQ/CLASSD_R3), J11.4
USBA_D+: IC3.68 (USBA_P), J15.3 (D+)
USBA_D-: IC3.67 (USBA_M), J15.2 (D-)
USBA_VBUS_5V: C33.1, IC3.57 (PD20/TIOA2/TWCK1/AD1), R48.1, R52.2
USBB_D+: IC3.71 (USBB_P), J13.3
USBB_D-: IC3.70 (USBB_M), J13.2
USBB_OVCUR: IC3.58 (PD19/PCK0/TWD1/AD0), IC8.2 (FLG), R53.2
USBB_POWR_EN: IC3.19 (PD21/EEPROM_TWD_PD21), IC8.1 (EN), JP10.2, R54.1
VBUS_USBA: C29.1, J15.1 (VBUS), JP1.1 (A), R48.2
VDDBU: C19.2, C21.2, IC3.55 (VDDBU), JP2.2, R2.2, R17.2, R18.2
VDDIN_3V3: C13.1, C14.1, C15.2, C16.2, C17.2, FB2.1, IC3.15 (VDDISC), IC3.16 (VDDIN_3V3_1), IC3.17 (VDDIN_3V3_2)
VDDSDHC: C18.2, C20.2, IC3.65 (VDDSDHC), JP4.2 (C), R34.1, R41.1, RN1.5 (R4.2), RN1.6 (R3.2), RN1.7 (R2.2), RN1.8 (R1.2), RN2.5 (R4.2), RN2.6 (R3.2), RN2.7 (R2.2), RN2.8 (R1.2)
VDD_3V3: C9.1, C24.1, C25.1, C26.1, C27.1, C30.1, C31.1, C34.1, C42.1, D1.2 (A), D2.2, FB4.1, IC2.2 (VDD), IC4.3 (WP#_(IO2)), IC4.7 (HOLD#_OR_RESET#_(IO3)), IC4.8 (VCC), IC5.12 (VCC_1), IC5.37 (VCC_2), IC6.8 (VCC), IC7.5 (VCC), IC9.3 (WP#_(IO2)), IC9.7 (HOLD#_OR_RESET#_(IO3)), IC9.8 (VCC), J5.1, J16.4, J17.10, J17.12, J18.9, J20.9, JP9.2, R9.2, R11.2, R13.2, R37.2, R39.2, R40.2, R43.1, R44.1, R45.1, R46.1, R47.1, R49.1, R50.1, R51.1, R53.1, R61.1
VDD_SDHC_1V8: FB1.1, IC2.6 (S2), JP4.1 (A)
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

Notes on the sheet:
Fast Ethernet
ONFI Compliance
Top layer power
separate PWR layer fill
Top/bottom layer power
* QSPI1 is only available on IOSET2
* FLEXCOM3_IO0-4 only available on IOSET2
* TWI1 is only available on IOSET2

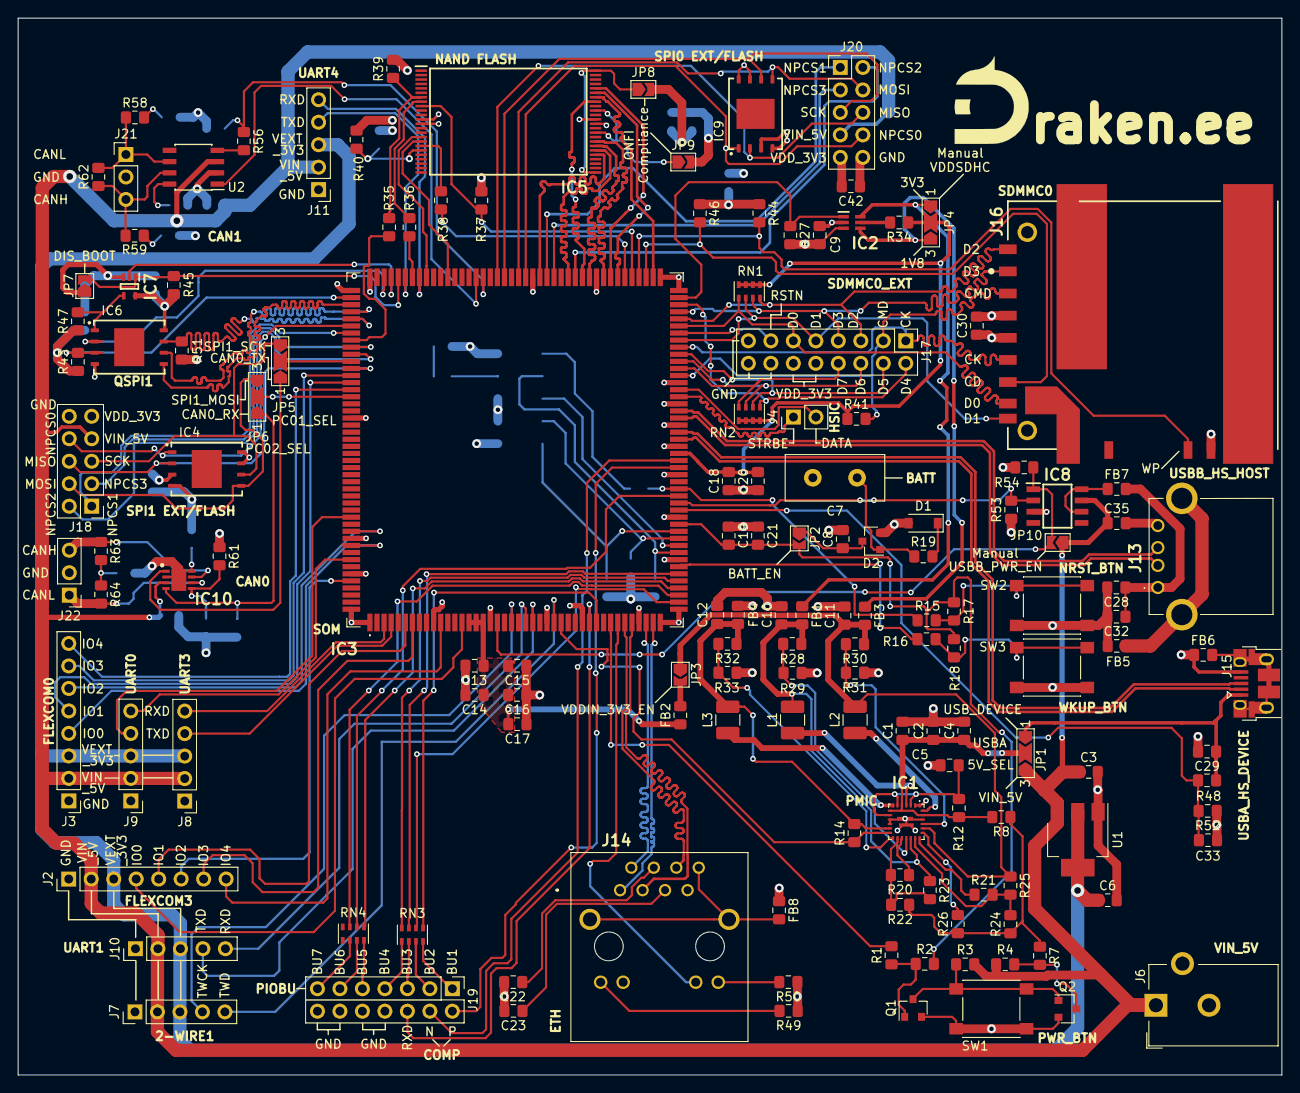
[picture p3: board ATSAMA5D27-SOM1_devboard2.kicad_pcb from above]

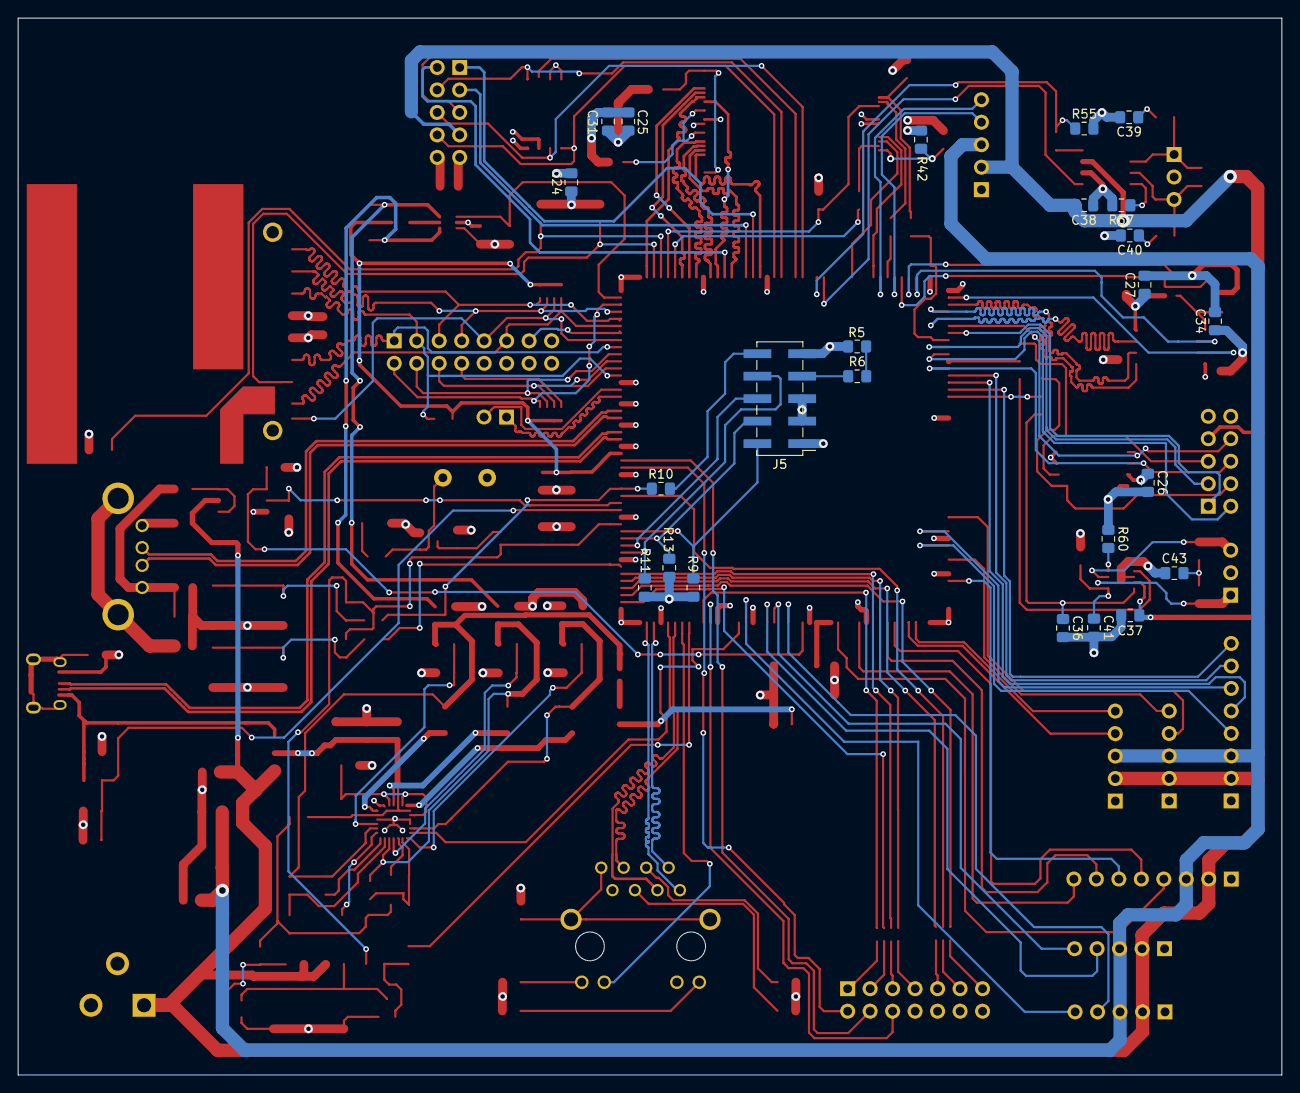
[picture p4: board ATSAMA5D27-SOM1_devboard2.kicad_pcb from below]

Board: 4 copper layers, 142.7 x 119.4 mm, 171 parts (24 on the bottom side), 181 nets.
